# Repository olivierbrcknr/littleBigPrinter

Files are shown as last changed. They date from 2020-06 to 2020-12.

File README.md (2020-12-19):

# LittleBigPrinter

In times of instant messaging, a small analog printer makes it way into the light, connecting people. It is meant to hang in a shared apartment, an office, or wherever you like and when a message arrives, it is meant to be seen by whoever sees it. No private hidden message, no hiding behind a smartphone screen and writing with one specific friend, no constant alert status, waiting for the next message.  

*LittleBigPrinter — the fax machine for millennials.*

Send a message here → [Messenger](https://little-big-printer-messenger.now.sh/)

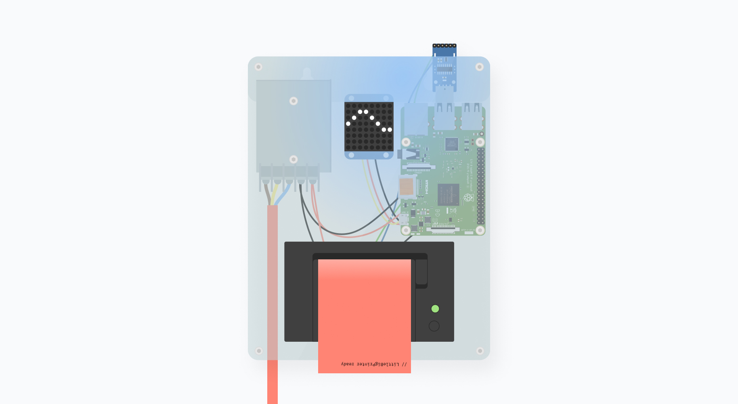
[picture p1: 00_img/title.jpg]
LittleBigPrinter


If you like this project, please also check out my other project → [FlipDot Communicator](https://github.com/olivierbrcknr/flipdot-communicator)

## Hardware Setup

*I refactored this project from an Raspberry Pi to an ESP32, as this is more lightweight code and runs more stable.*

### Components

* [ESP32](https://www.az-delivery.de/en/products/esp32-developmentboard)
* [Adafruit Thermal Printer](https://www.adafruit.com/product/597)
* [LED Matrix](https://www.adafruit.com/product/1080)
* [Power Supply 5V 3A](https://www.meanwell-web.com/en-gb/ac-dc-single-output-enclosed-power-supply-output-rs--15--5)

### Case

What is needed to build the case and wall mount:

* 230 ✕ 160 mm, 3 mm thick acrylic glass. You can find the laser file here: [`00_case/laser.dxf`](00_case/laser.dxf)
* 12 M3✕10 mm screws (+ 2-3 additional ones for cutting threads)
* 4 M3 nuts
* 4 aluminium tubes, Ø5 mm (inside ~ Ø2.5mm to cut in a M3 thread) 
* A **three** core cable for power supply

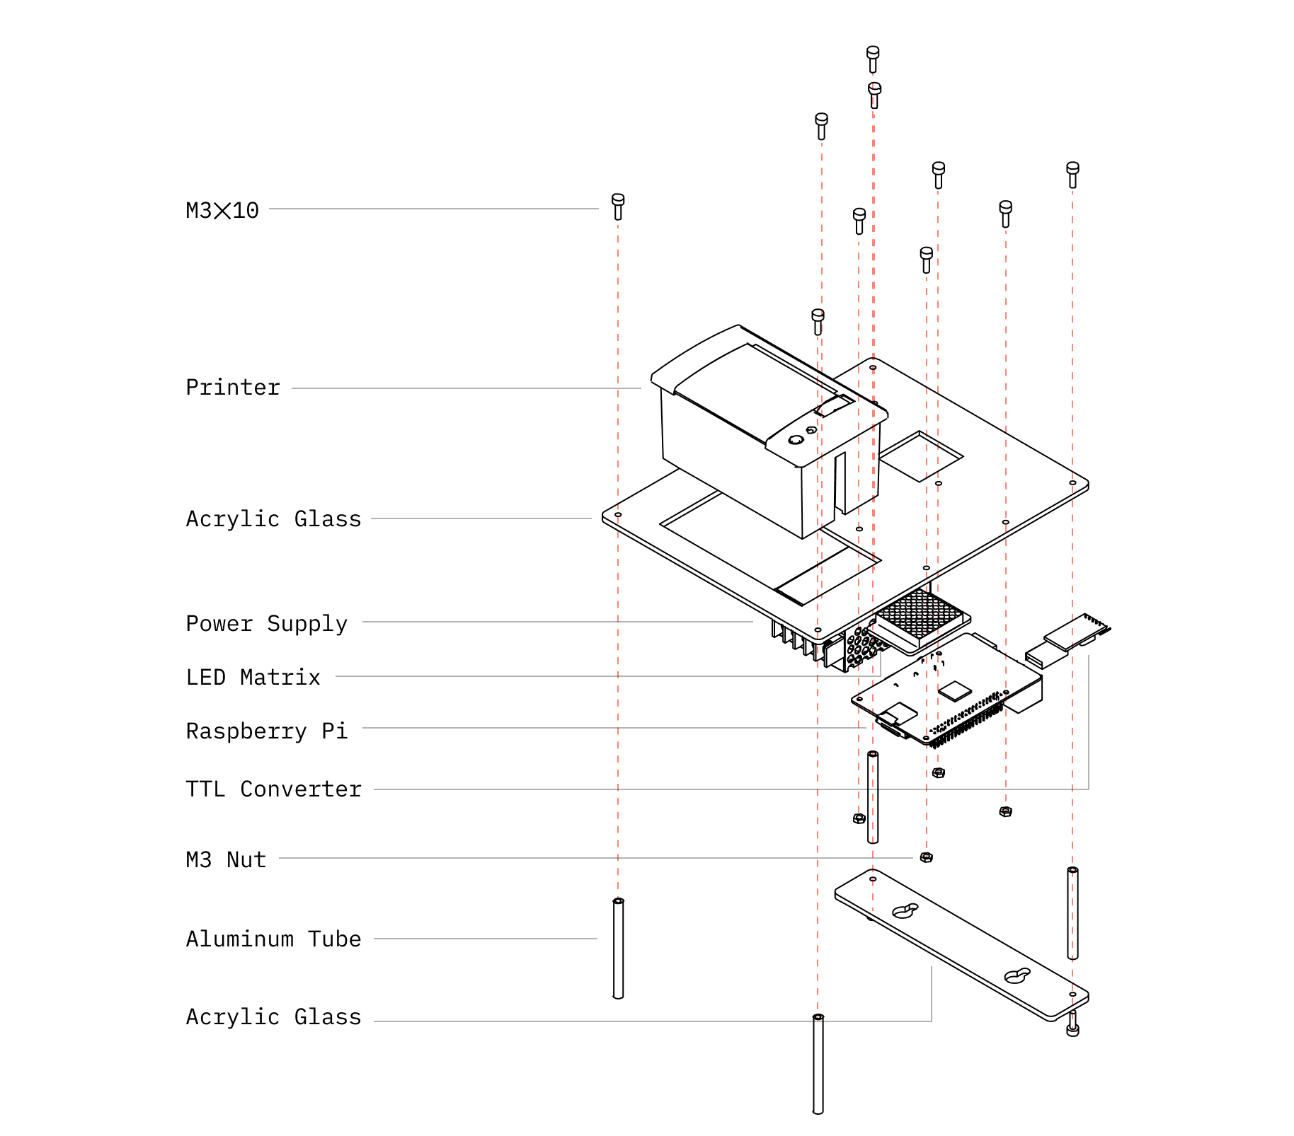
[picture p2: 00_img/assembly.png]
Assembly


### Pin Setup

|ESP32 |Components | 
|---|---|
|Vin |Power Supply + |
|GND |Power Supply - |
|5V |LED Matrix + |
|GND |LED Matrix - |
|GPIO 21 |LED Matrix D |
|GPIO 22 |LED Matrix C |
|GND |Printer Serial GND |
|GPIO 19 |Printer Tx |
|GPIO 18 |Printer Rx |

## Software

### Flashing The ESP32

The software for the ESP32 is built using the [Arduino IDE](https://www.arduino.cc/en/software). You can find all the files here → [`LittleBigPrinter-Software/`](LittleBigPrinter-Software)

### Libraries to install

You will need to install these libraries for the code to work:

* [ESP32](https://github.com/espressif/arduino-esp32)
* [Firebase ESP32](https://github.com/mobizt/Firebase-ESP32)
* [Adafruit LED Backpack](https://github.com/adafruit/Adafruit_LED_Backpack)
* [Adafruit Thermal Printer Library](https://github.com/adafruit/Adafruit-Thermal-Printer-Library)
* [Adafruit RTClib](https://github.com/adafruit/RTClib)

### Flash the ESP32

Next, open the [`.ino`](LittleBigPrinter-Software/LittleBigPrinter-Software.ino) file. Add your credentials to the `credentials.h` file. The placeholders are these ones:

```cpp
#define FIREBASE_HOST "YOUR_FIREBASE_PROJECT.firebaseio.com"
#define FIREBASE_AUTH "YOUR_FIREBASE_DATABASE_SECRET"
#define WIFI_SSID "YOUR_WIFI_SSID"
#define WIFI_PASSWORD "YOUR_WIFI_PASSWORD"
```

If you are not sure where to find the Firebase credentials, this [stackoverflow question](https://stackoverflow.com/questions/37418372/firebase-where-is-my-account-secret-in-the-new-console) will help you.

Finally flash it onto the board. Now you should be all set up!

## ToDos

- [ ] Implement multi printer usage (per IDs within the database)
- [ ] Add a buzzer to acoustically inform about new messages
- [ ] Add a RGB LED and button (or something completely different) to change the paper color entry

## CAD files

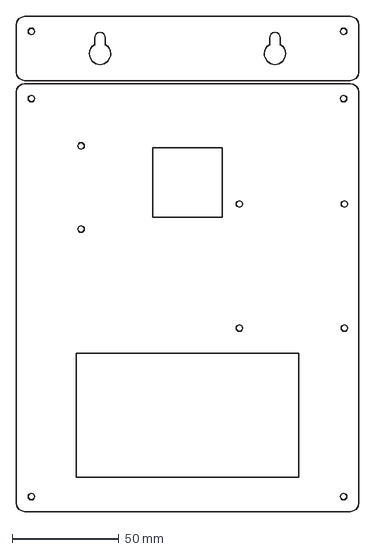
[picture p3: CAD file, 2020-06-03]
00_case/laser.dxf
160.0 x 231.4 mm

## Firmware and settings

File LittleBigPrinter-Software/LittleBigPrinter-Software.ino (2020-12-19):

#include "credentials.h"
#include "icons.h"

#include <RTClib.h>

// Firebase
#include <WiFi.h>
#include <FirebaseESP32.h>

String db = "/LittleBigPrinter";
String path = db + "/Messages";

FirebaseData firebaseData;
FirebaseJsonData jsonData;
FirebaseJson json;
FirebaseJsonArray arr;
void printResult(FirebaseData &data);

// Printer
#include <Adafruit_Thermal.h>
#include <SoftwareSerial.h>
#define TX_PIN 19 // Arduino transmit  YELLOW WIRE  labeled RX on printer
#define RX_PIN 18 // Arduino receive   GREEN WIRE   labeled TX on printer

SoftwareSerial mySerial(RX_PIN, TX_PIN); // Declare SoftwareSerial obj first
Adafruit_Thermal printer(&mySerial);     // Pass addr to printer constructor

// Matrix
#include <Wire.h>
#include <Adafruit_GFX.h>
#include "Adafruit_LEDBackpack.h"

Adafruit_8x8matrix matrix = Adafruit_8x8matrix();

int sendDataPrevMillis = 0;
int initCheckTime = 3000;
int checkTime = 5 * 1000; // in ms

bool isPrinting = false;

void setup() {

  Serial.begin(115200);

  // init WiFi
  WiFi.begin(WIFI_SSID, WIFI_PASSWORD);
  Serial.print("Connecting to Wi-Fi");
  while (WiFi.status() != WL_CONNECTED)
  {
    Serial.print(".");
    delay(300);
  }
  Serial.println();
  Serial.print("Connected with IP: ");
  Serial.println(WiFi.localIP());
  Serial.println();

  // init Firebase
  Firebase.begin(FIREBASE_HOST, FIREBASE_AUTH);
  Firebase.reconnectWiFi(true);
  
  Firebase.setReadTimeout(firebaseData, 1000 * 60);
  Firebase.setwriteSizeLimit(firebaseData, "small");
  firebaseData.setResponseSize(12288);

  Firebase.setFloatDigits(2);
  Firebase.setDoubleDigits(6);

  if (!Firebase.beginStream(firebaseData, path))
  {
      Serial.println("------------------------------------");
      Serial.println("Can't begin stream connection...");
      Serial.println("REASON: " + firebaseData.errorReason());
      Serial.println("------------------------------------");
      Serial.println();
  }

  matrix.begin(0x70);

  Anim_StartUp();

  pinMode(7, OUTPUT); digitalWrite(7, LOW);
  mySerial.begin(19200);
  printer.begin(); 
  printer.println(F("// LittleBigPrinter is ready"));
  printer.println(F(" "));
  printer.println(F(" "));
  Serial.println("// LittleBigPrinter is ready");
  
  printer.sleep();
}

void loop() {

  if (millis() - sendDataPrevMillis > initCheckTime){
    sendDataPrevMillis = millis();
    checkForMessages();
    initCheckTime = checkTime;
  }
  
}

void checkForMessages() {
  Serial.println("------------------------------------");
  Serial.println("Get Data...");
  if (Firebase.get(firebaseData, path))
  {   
    
    Serial.println("------------------------------------");
    Serial.println();

    if( firebaseData.dataType() == "json" ){

      FirebaseJson &json = firebaseData.jsonObject();

      Serial.println("Pretty printed JSON data:");
      String jsonStr;
      json.toString(jsonStr, true);
      Serial.println(jsonStr);
      Serial.println(); 
      
      size_t len = json.iteratorBegin();
      String key, value = "";
      int type = 0;

      String mName, mMsg, mDate, mID = "";
      bool isNewMessage = false;

      int messageCount = 0;
      
      for (size_t i = 0; i < len; i++)
      {
        json.iteratorGet(i, type, key, value);
        if( messageCount <= 1 ){

          if(value.indexOf("{") >= 0){
            if( messageCount < 1 ){
              mID = key;     
            }
            messageCount++;
          } 

          if(key.indexOf("Name") >= 0 ){
            mName = value;
          }

          if(key.indexOf("Message") >= 0 ){
            mMsg = value;
          }

          if(key.indexOf("Date") >= 0 ){
            mDate = value;
          }

        } // endIf isNewMessage
      }
      json.iteratorEnd(); 
      if( messageCount > 0 ){
        printMessage( mName, mMsg, mDate, mID );            
      }
    }
  } else {
    Serial.println("FAILED");
    Serial.println("REASON: " + firebaseData.errorReason());
    Serial.println("------------------------------------");
    Serial.println();
  }
}

// delete message
void deleteCurrentMessage( String id ) {
  Firebase.deleteNode(firebaseData, path + "/" + id);
}

// move to backup DB
void moveCurrentMessage( String n, String m, String t, String id ) {
  FirebaseJson json;
  json.set("Name", n);
  json.set("Message", m);
  json.set("Date", t);
  Firebase.pushJSON(firebaseData, db + "/Printed", json );
  deleteCurrentMessage( id );
}


void printMessage( String n, String m, String t, String id ){

  Anim_PrintingMessage();

  String whiteSpace = "";
  int whiteSpaceCount = 18 - n.length();
  for( int i = 0; i < whiteSpaceCount; i++ ){
    whiteSpace = whiteSpace + " ";
  }

  isPrinting = true;

  Serial.print("Printing message from ");
  Serial.println(n);
 
  printer.wake();
  printer.setDefault(); 

  // printer.println(F("Some Message"));
  printer.print(n);
  printer.print(whiteSpace);
  printer.println(t);
  printer.println(F("------"));
  printer.println(m);

  printer.println(F(" "));
  printer.println(F(" "));
  printer.println(F(" "));
  
  printer.sleep(); 

  isPrinting = false;

  moveCurrentMessage(n,m,t,id);

  clearMatrix();
}


void clearMatrix(){
  matrix.clear();
  matrix.writeDisplay(); 
}

void Anim_PrintingMessage(){
  matrix.clear();
  matrix.drawBitmap(0, 0, sinus_icn, 8, 8, LED_ON);
  matrix.writeDisplay();
}

void Anim_StartUp(){

  for( int i = 0; i < 8; i++ ){
    matrix.clear();
    matrix.drawLine(0,i,7,i, LED_ON);
    matrix.writeDisplay();
    delay(100);
  } 
  clearMatrix();
}

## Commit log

2019-05-13 Include Image Print Test
2019-05-17 Included button and exit fn
2019-05-19 Included IMAP, mail print init and case dxf
    [laser.dxf]
2020-12-16 Init ESP32 code
2020-12-19 Enable realtime db print
2020-12-19 Add basic LED matrix support
